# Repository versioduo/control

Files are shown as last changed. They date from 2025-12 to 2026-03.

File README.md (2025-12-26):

# control

⚙️ Instrument Controller

## Board

board

## Schematic

[PDF](control.pdf)

## Bill Of Materials

[Interactive BOM](https://htmlpreview.github.io/?https://github.com/versioduo/control/main/control-bom.html)

# Copying
Anyone can use this public domain work without having to seek authorisation, no one can ever own it.

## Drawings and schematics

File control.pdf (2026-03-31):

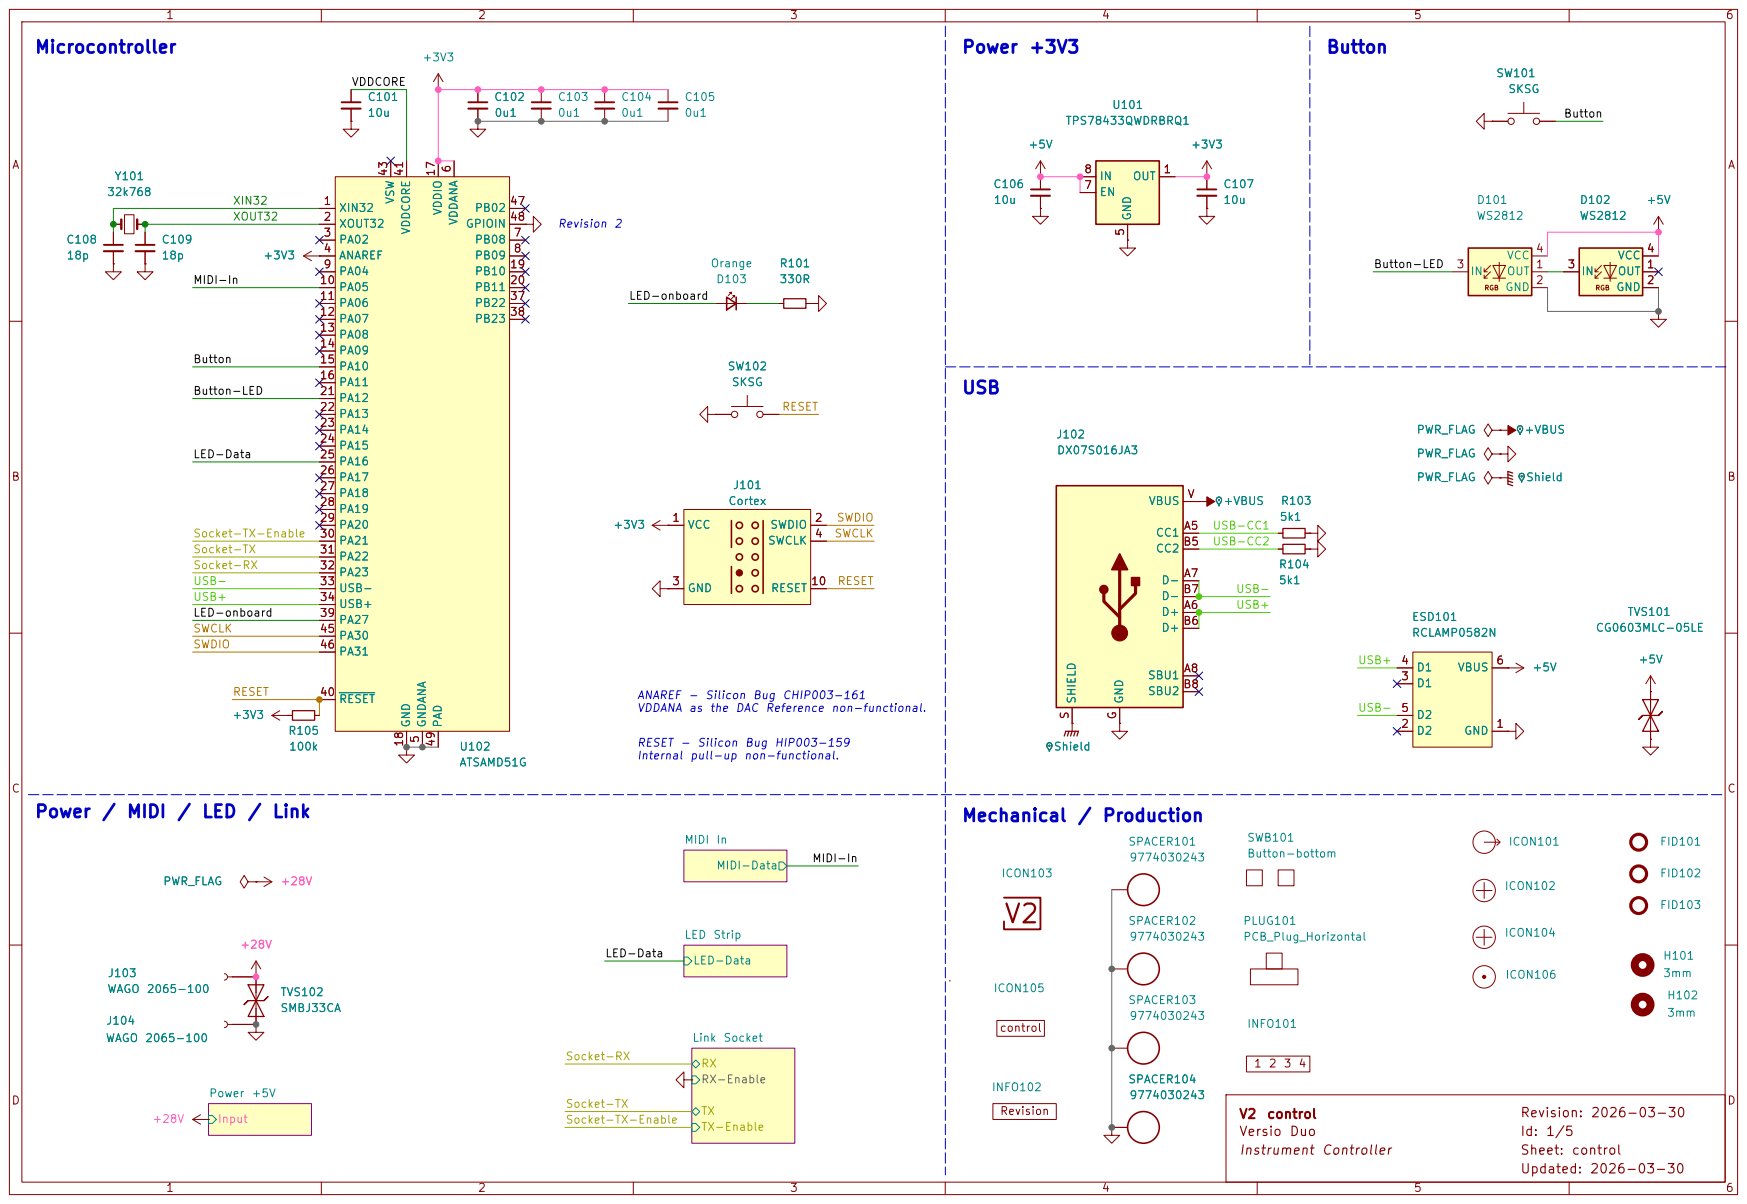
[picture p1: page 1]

Internal pull-up non-functional. Power / MIDI / LED / Link

Link Socket LED-Data

Socket-TX-Enable Socket-RX

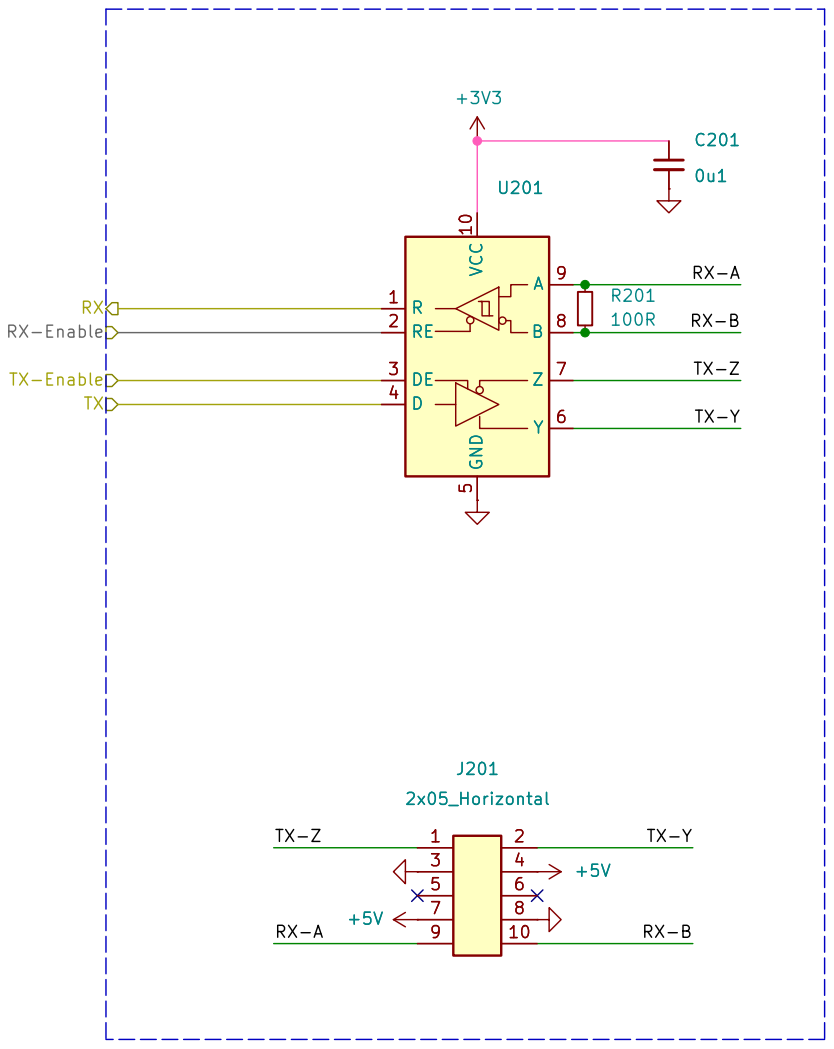
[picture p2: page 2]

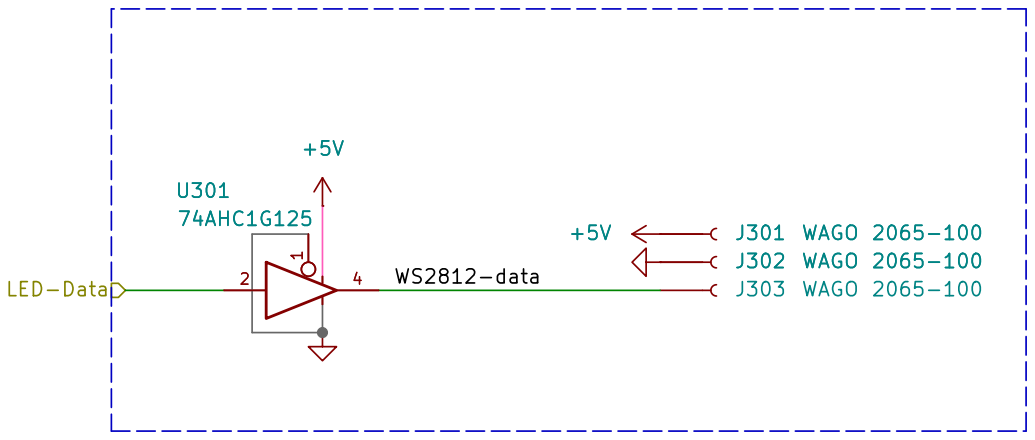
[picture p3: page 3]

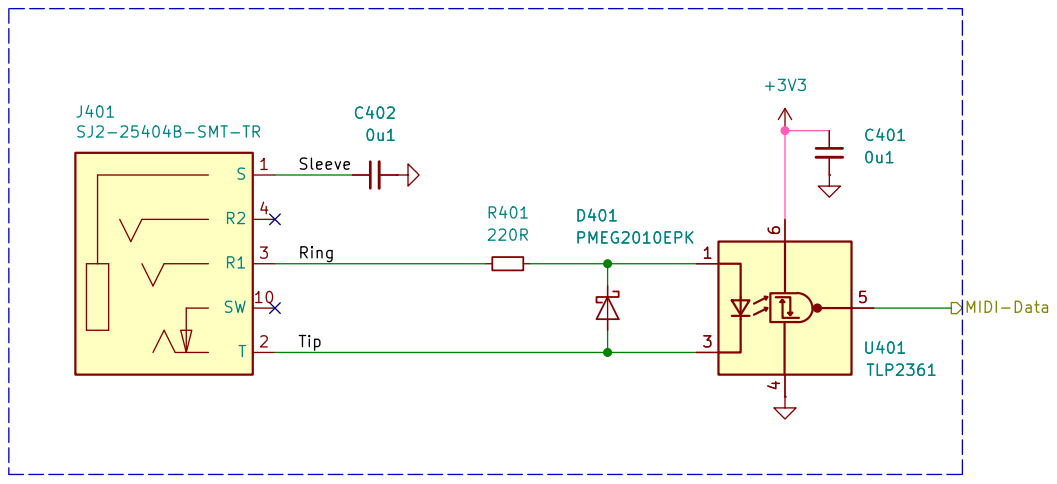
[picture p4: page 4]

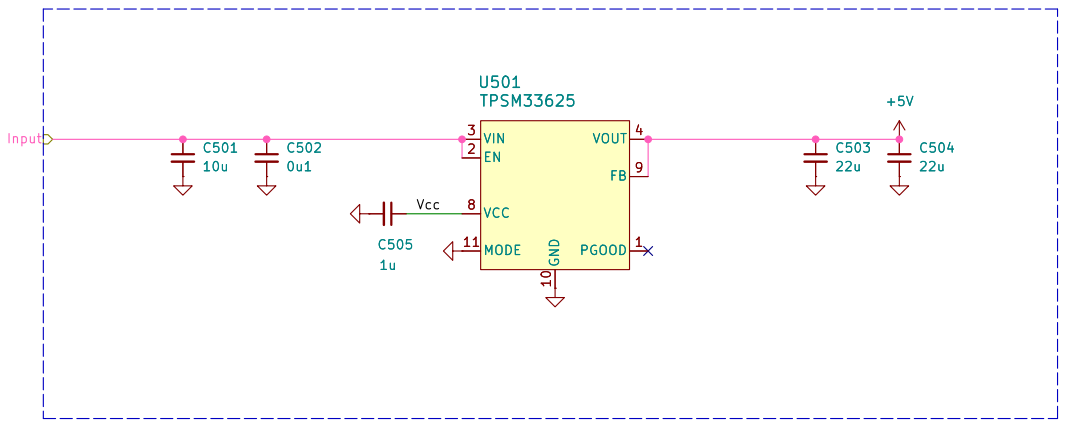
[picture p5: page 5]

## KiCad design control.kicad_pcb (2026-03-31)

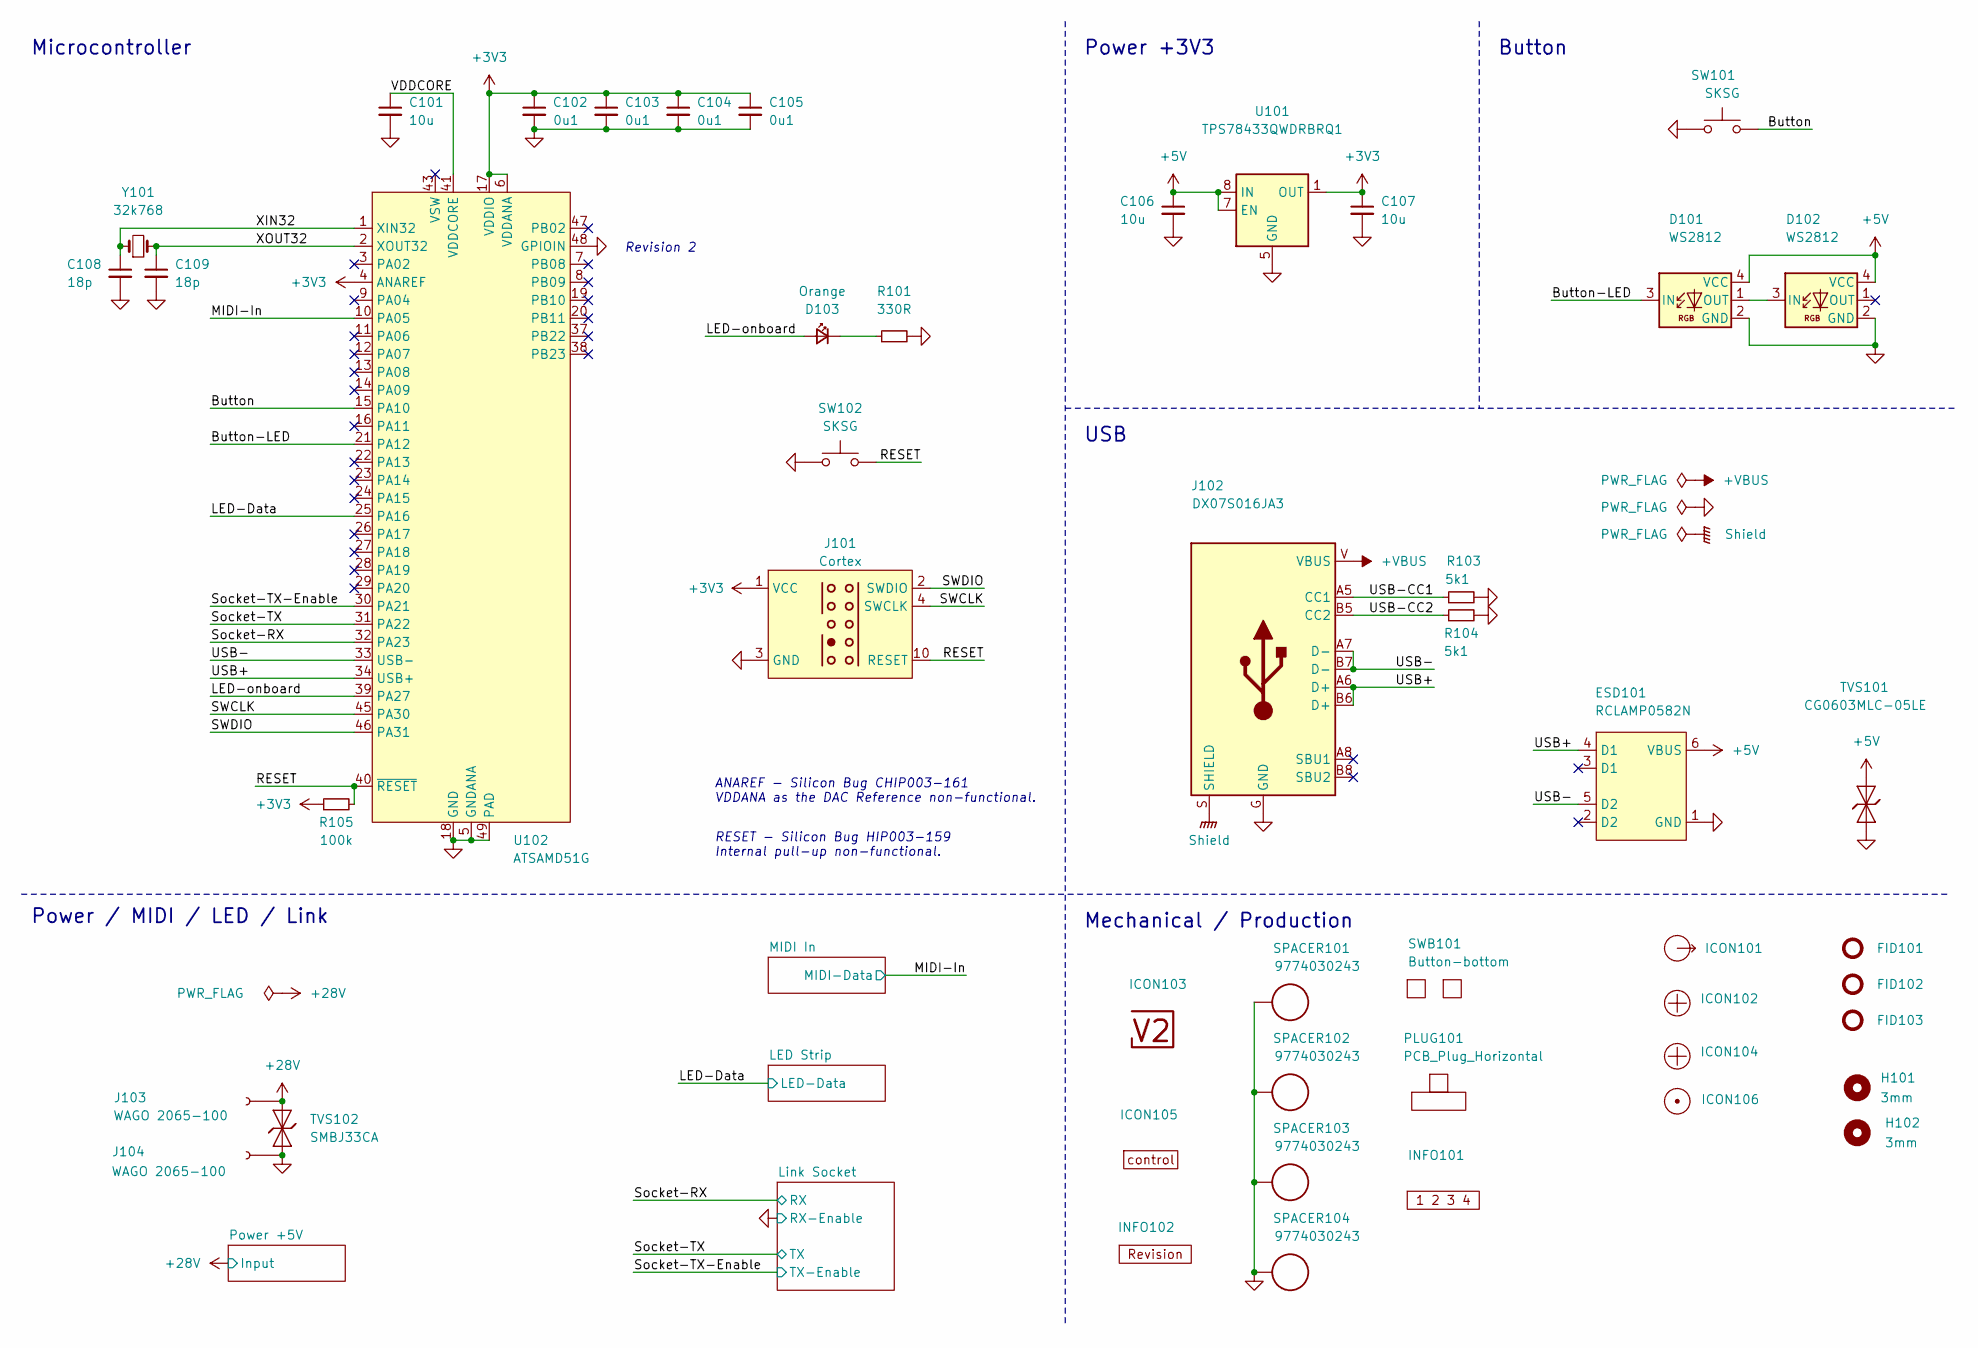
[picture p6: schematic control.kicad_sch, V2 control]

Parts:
C101: 10u; C_0603; Rating 10V; Mouser 810-C1608X6S1A106M
C102, C103, C104, C105: 0u1; C_0603; Rating 50V; Mouser 810-CGA3E2X7R1H104MA
C106, C107: 10u; C_0805; Rating 25V; Mouser 810-C2012X5R1E106K
C108, C109: 18p; C_0603; Rating 50V; Mouser 810-CGA3E2C0G1H180J
D101, D102: WS2812; WS2812-2020; LCSC C965555
D103: Orange; LED_0603; Mouser 755-SML-D12D1WT86
ESD101: RCLAMP0582N; SLP1210N6; Mouser 947-RCLAMP0582N.TCT
FID101, FID102, FID103: Fiducial_Paste; Fiducial_0.5mm_Mask1mm_Paste
H101, H102: 3mm; MountingHole_3mm
ICON101: Arrow_Out
ICON102, ICON104: Plus; Plus_Small
ICON103: V2-logo; Logo_Small
ICON105: Board_control; Board_control_Small
ICON106: Dot; Dot_Small
INFO101: Layer_Numbers
INFO102: Revision
J101: Cortex
J102: DX07S016JA3; JAE_DX07S016JA3; Mouser 656-DX07S016JA3R1500
J103, J104: WAGO 2065-100; 2065-100
PLUG101: PCB_Plug_Horizontal
R101: 330R; R_0603; Rating 100mW; Mouser 71-CRCW0603330RFKEAC
R103, R104: 5k1; R_0603; Rating 100mW; Mouser 71-CRCW06035K10FKEAC
R105: 100k; R_0603; Rating 100mW; Mouser 71-CRCW0603100KFKEAC
SPACER101, SPACER102, SPACER103, SPACER104: 9774030243
SW101, SW102: SKSG; Rating 1.6N; Mouser 688-SKSGACE010
SWB101: Button-bottom; PCB_Button-bottom
TVS101: CG0603MLC-05LE; D_0603; Rating 5V; Mouser 652-CG0603MLC-05LE
TVS102: SMBJ33CA; D_SMB; Rating 33V; Mouser 652-SMBJ33CA-Q
U101: TPS78433QWDRBRQ1; VSON-8-1_3x3mm_P0.65_EP1.65x2.4mm; Mouser 595-TPS78433QWDRBRQ1
U102: ATSAMD51G; QFN-48-1EP_7x7mm_P0.5mm_EP5.45x5.45mm_ThermalVias; Mouser 556-ATSAMD51G19AMU
Y101: 32k768; Crystal_SMD_3215-2Pin_3.2x1.5mm; Mouser 815-ABS0716632.768KT

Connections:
+3V3: C102.1, C103.1, C104.1, C105.1, C107.1, J101.1 (VCC), R105.1, U101.1 (OUT), U102.4 (ANAREF), U102.6 (VDDANA), U102.17 (VDDIO), U102.36 (VDDIO), U102.44 (VDDIO); also elsewhere on the board
+5V: C106.1, D101.4 (VCC), D102.4 (VCC), ESD101.6 (VBUS), TVS101.2 (A), U101.7 (EN), U101.8 (IN); also elsewhere on the board
+28V: J103.1, TVS102.2 (A); also elsewhere on the board
/+VBUS: J102.V (VBUS)
/Button: SW101.2, U102.15 (PA10)
/Button-LED: D101.3 (IN), U102.21 (PA12)
/LED-Data: U102.25 (PA16); also elsewhere on the board
/LED-onboard: D103.2 (A), U102.39 (PA27)
/MIDI-In: U102.10 (PA05); also elsewhere on the board
/RESET: J101.10 (RESET), R105.2, SW102.2, U102.40 (~RESET)
/SWCLK: J101.4 (SWCLK), U102.45 (PA30)
/SWDIO: J101.2 (SWDIO), U102.46 (PA31)
/Shield: J102.S (SHIELD)
/Socket-RX: U102.32 (PA23); also elsewhere on the board
/Socket-TX: U102.31 (PA22); also elsewhere on the board
/Socket-TX-Enable: U102.30 (PA21); also elsewhere on the board
/USB+: ESD101.4 (D1), J102.A6 (D+), J102.B6 (D+), U102.34 (USB+)
/USB-: ESD101.5 (D2), J102.A7 (D-), J102.B7 (D-), U102.33 (USB-)
/USB-CC1: J102.A5 (CC1), R103.1
/USB-CC2: J102.B5 (CC2), R104.1
/VDDCORE: C101.1, U102.41 (VDDCORE)
/XIN32: C108.1, U102.1 (XIN32), Y101.1
/XOUT32: C109.1, U102.2 (XOUT32), Y101.2
GND: C101.2, C102.2, C103.2, C104.2, C105.2, C106.2, C107.2, C108.2, C109.2, D101.2 (GND), D102.2 (GND), ESD101.1 (GND), J101.3 (GND), J101.5 (GND), J102.G (GND), J104.1, R101.2, R103.2, R104.2, SPACER101.1 (1_1), SPACER102.1 (1_1), SPACER103.1 (1_1), SPACER104.1 (1_1), SW101.1, SW102.1, TVS101.1 (K), TVS102.1 (K), U101.5 (GND), U101.9 (GND), U102.5 (GNDANA), U102.18 (GND), U102.35 (GND), U102.42 (GND), U102.48 (GPIOIN), U102.49 (PAD); also elsewhere on the board
unnamed: D101.1 (OUT), D102.3 (IN)
unnamed: D103.1 (K), R101.1

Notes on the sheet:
ANAREF -  Silicon Bug CHIP003-161 VDDANA as the DAC Reference non-functional.
Power / MIDI / LED / Link
RESET -  Silicon Bug HIP003-159 Internal pull-up non-functional.
Button
Revision 2
Power +3V3
Mechanical / Production
Microcontroller
USB

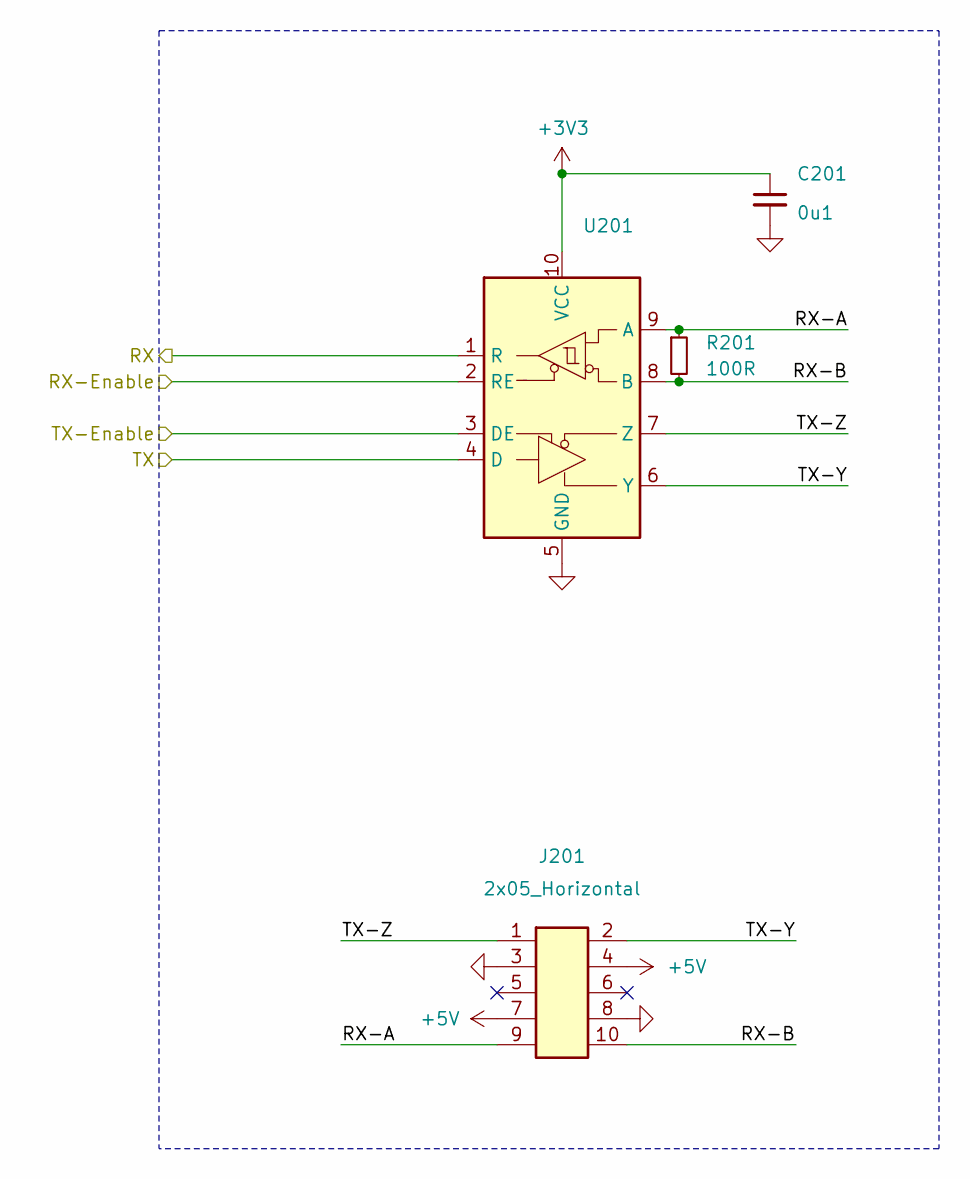
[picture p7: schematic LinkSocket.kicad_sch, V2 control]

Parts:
C201: 0u1; C_0603; Rating 50V; Mouser 810-CGA3E2X7R1H104MA
J201: 2x05_Horizontal; PinHeader_2x05_P1.27mm_Horizontal; Mouser 649-200211120001T4LF
R201: 100R; R_0603; Rating 330mW; Mouser 71-CRCW0603100RFKEAH
U201: VSON-10-4-1EP_3x3mm_P0.5mm_EP1.65x2.4mm_ThermalVias

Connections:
+3V3: C201.1, U201.10 (VCC); also elsewhere on the board
+5V: J201.4, J201.7; also elsewhere on the board
/Link Socket/RX-A: J201.9, R201.1, U201.9 (A)
/Link Socket/RX-B: J201.10, R201.2, U201.8 (B)
/Link Socket/TX-Y: J201.2, U201.6 (Y)
/Link Socket/TX-Z: J201.1, U201.7 (Z)
/Socket-RX: U201.1 (R); also elsewhere on the board
/Socket-TX: U201.4 (D); also elsewhere on the board
/Socket-TX-Enable: U201.3 (DE); also elsewhere on the board
GND: C201.2, J201.3, J201.8, U201.2 (RE), U201.5 (GND), U201.11 (GND); also elsewhere on the board

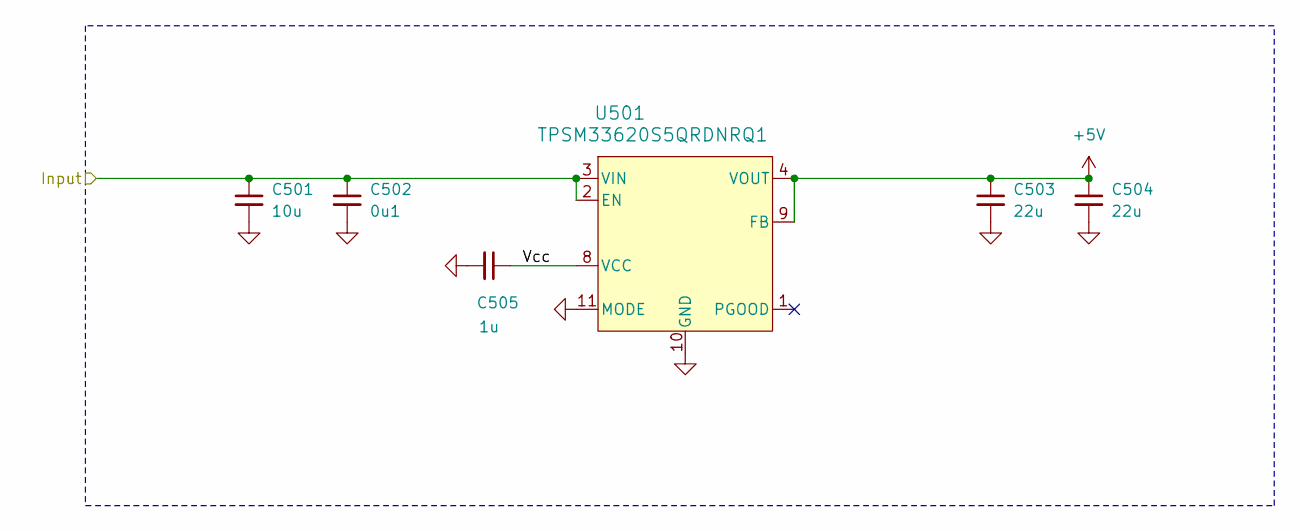
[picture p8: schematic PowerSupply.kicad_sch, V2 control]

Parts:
C501: 10u; C_1210; Rating 50V; Mouser 810-CNC6P1X7R1H106K2
C502: 0u1; C_0603; Rating 50V; Mouser 810-CGA3E2X7R1H104MA
C503, C504: 22u; C_1210; Rating 25V; Mouser 810-CGA6P3X7R1E226M5
C505: 1u; C_0603; Rating 50V; Mouser 810-CGA3E3X7R1H105K0
U501: TPSM33620S5QRDNRQ1; QFN-11; Rating 2A; Mouser 595-SM33620S5QRDNRQ1

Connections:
+5V: C503.1, C504.1, U501.4 (VOUT), U501.9 (FB); also elsewhere on the board
+28V: C501.1, C502.1, U501.2 (EN), U501.3 (VIN); also elsewhere on the board
/Power +5V/Vcc: C505.1, U501.8 (VCC)
GND: C501.2, C502.2, C503.2, C504.2, C505.2, U501.10 (GND), U501.11 (MODE); also elsewhere on the board

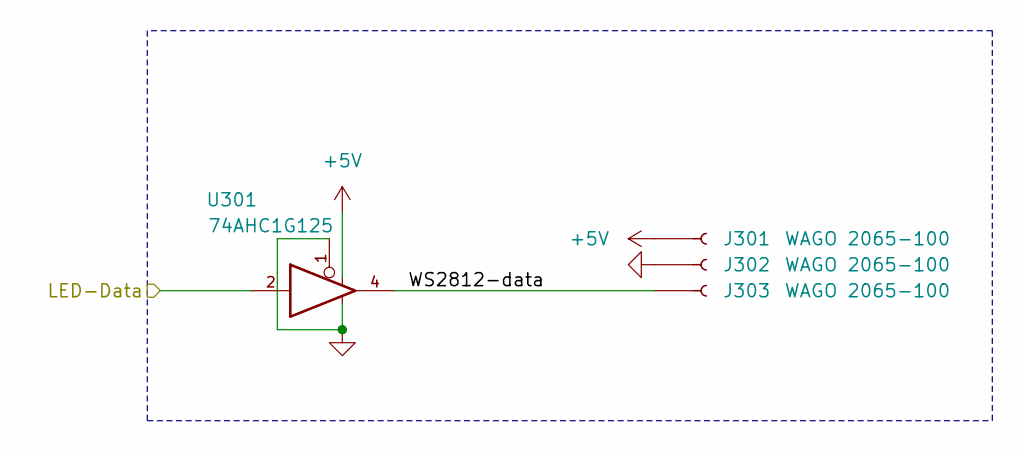
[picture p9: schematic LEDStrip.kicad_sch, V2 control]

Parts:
J301, J302, J303: WAGO 2065-100; 2065-100
U301: 74AHC1G125; SOT-23-5; Mouser 595-SN74AHC1G125DBVR

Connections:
+5V: J301.1, U301.5; also elsewhere on the board
/LED Strip/WS2812-data: J303.1, U301.4
/LED-Data: U301.2; also elsewhere on the board
GND: J302.1, U301.1, U301.3; also elsewhere on the board

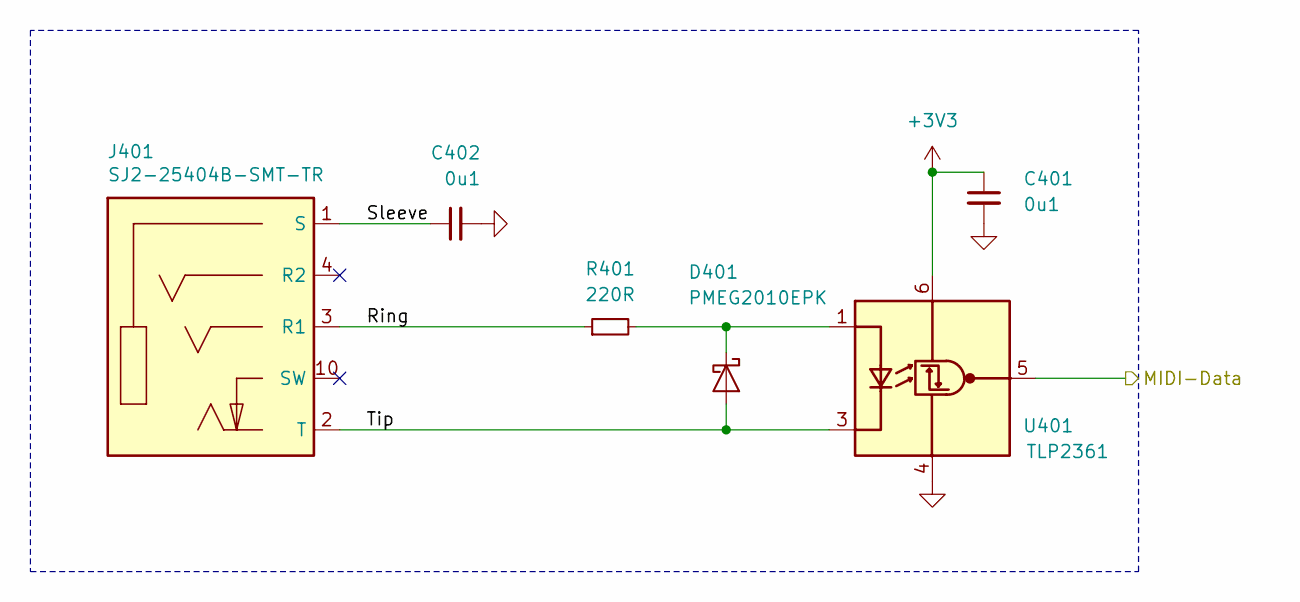
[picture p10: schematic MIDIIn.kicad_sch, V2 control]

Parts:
C401, C402: 0u1; C_0603; Rating 50V; Mouser 810-CGA3E2X7R1H104MA
D401: PMEG2010EPK; D_SOD-1608; Rating 20V; Mouser 771-PMEG2010EPK
J401: SJ2-25404B-SMT-TR; CUI_SJ2-25404B-SMT-TR; Mouser 490-SJ2-25404BSMT-TR
R401: 220R; R_0603; Rating 330mW; Mouser 71-CRCW0603220RFKEAH
U401: TLP2361; SO-5-6_4.55x3.7mm_P1.27mm; Mouser 757-TLP2361TPRE

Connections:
+3V3: C401.1, U401.6 (VDD); also elsewhere on the board
/MIDI In/Ring: J401.3 (R1), R401.1
/MIDI In/Sleeve: C402.1, J401.1 (S)
/MIDI In/Tip: D401.2 (A), J401.2 (T), U401.3 (K)
/MIDI-In: U401.5 (VO); also elsewhere on the board
GND: C401.2, C402.2, U401.4 (GND); also elsewhere on the board
unnamed: D401.1 (K), R401.2, U401.1 (A)

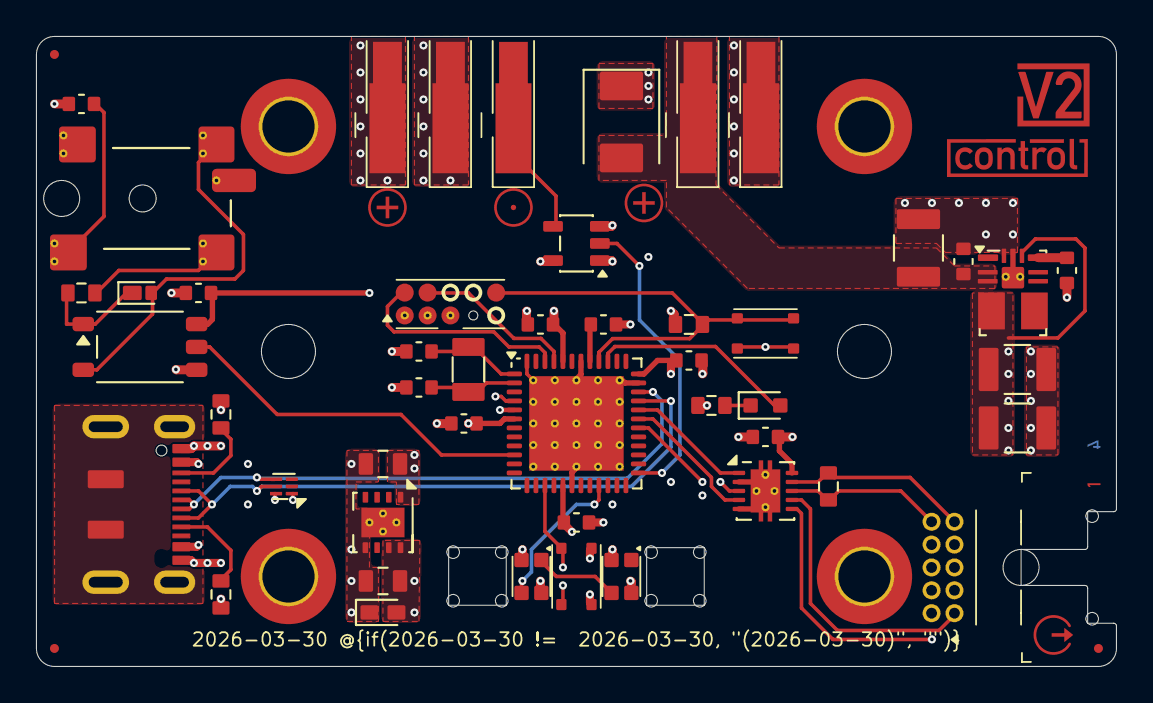
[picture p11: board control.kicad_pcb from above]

Board: 4 copper layers, 60.0 x 35.0 mm, 67 parts (0 on the bottom side), 34 nets.

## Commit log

2025-11-28 Link termination
    [LinkSocket.kicad_sch, control.kicad_pcb]
2025-12-26 Update project name and BOM link in README
2026-02-13 Replace Order_Number
    [LEDStrip.kicad_sch, LinkSocket.kicad_sch, MIDIIn.kicad_sch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]
2026-02-15 Update Library
    [LEDStrip.kicad_sch, LinkSocket.kicad_sch, MIDIIn.kicad_sch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]
2026-03-14 Update ESD suppressor
    [LinkSocket.kicad_sch, MIDIIn.kicad_sch, PowerSupply.kicad_sch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]
2026-03-30 Replace diode
    [LEDStrip.kicad_sch, LinkSocket.kicad_sch, MIDIIn.kicad_sch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]
2026-03-31 Replace step-down
    [PowerSupply.kicad_sch, control.kicad_pcb, control.kicad_sch]
2026-05-11 Good Bye Imperial
    [LinkSocket.kicad_sch, MIDIIn.kicad_sch, PowerSupply.kicad_sch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]
